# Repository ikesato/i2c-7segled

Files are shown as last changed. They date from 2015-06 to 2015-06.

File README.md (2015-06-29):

概要
====

- I2C を使用した7セグメントLED表示器です
- おもに Raspberry PI からの利用を想定してます  
 Raspberry PI からシェルコマンドを利用して直接制御可能
- 点滅、スクロール機能
- 最大で８つのページ切り替え機能

### パーツ

- PIC18F14K50 (SOIC)  
 1.25mm ピッチ

- TD62083 (SOIC)  
 1.25mm ピッチ

- ダイナミック接続４桁高輝度赤色７セグメントＬＥＤ表示器　カソードコモン　カソード共通接続  
 http://akizukidenshi.com/catalog/g/gI-03955/

- チップ抵抗  
 270Ω  1/4W x 8  

- チップコンデンサ  
 0.1uF  x2

### I2C通信仕様

- 通信速度 100kHz
- I2C スレーブ
- ライト要求 (Master -> Slaveへのライト要求) のみ

### コマンド

| address | data | description |
|---|---|---|
| 0x00 | なし | リセット |
| 0x01 | なし | LCD消灯 |
| 0x02 | 1..8 | 最大ページ数設定  |
| 0x03 | 0..255 | スクロール速度設定 (0.1秒 * (指定値+1)) *1  |
| 0x04 | 0..255 | ページ切り替え速度設定 (0.1秒 * (指定値+1))  |
| 0x05 | 0..255 | 点滅速度設定 (0.1秒 * (指定値+1))  |
| 0x06 | 0..1 | スクロール設定 (0:disable 1:enable)|
| 0x07 | 0..1 | 点滅設定 (0:disable 1:enable) |
| 0x10 | 0..7 | カレントページ設定 *2 |
| 0x11 | 文字列 | 描画文字列を指定、終端は 0x00 を指定します *3 |

*1 ... 文字のスクロール速度になります。例えば 19 を指定した場合 0.1*(19+1) で2秒単位にスクロールします。  
*2 ... 0 から数えるページ数を指定します。範囲は 0 から 最大ページ数-1 になります。  
*3 ... 描画文字列は ASCII コードで指定します。表示可能文字は数字、スペース、ハイフン、アンダースコア、パイプ、アルファベット（大文字、小文字）、ピリオドです。  

### 回路図

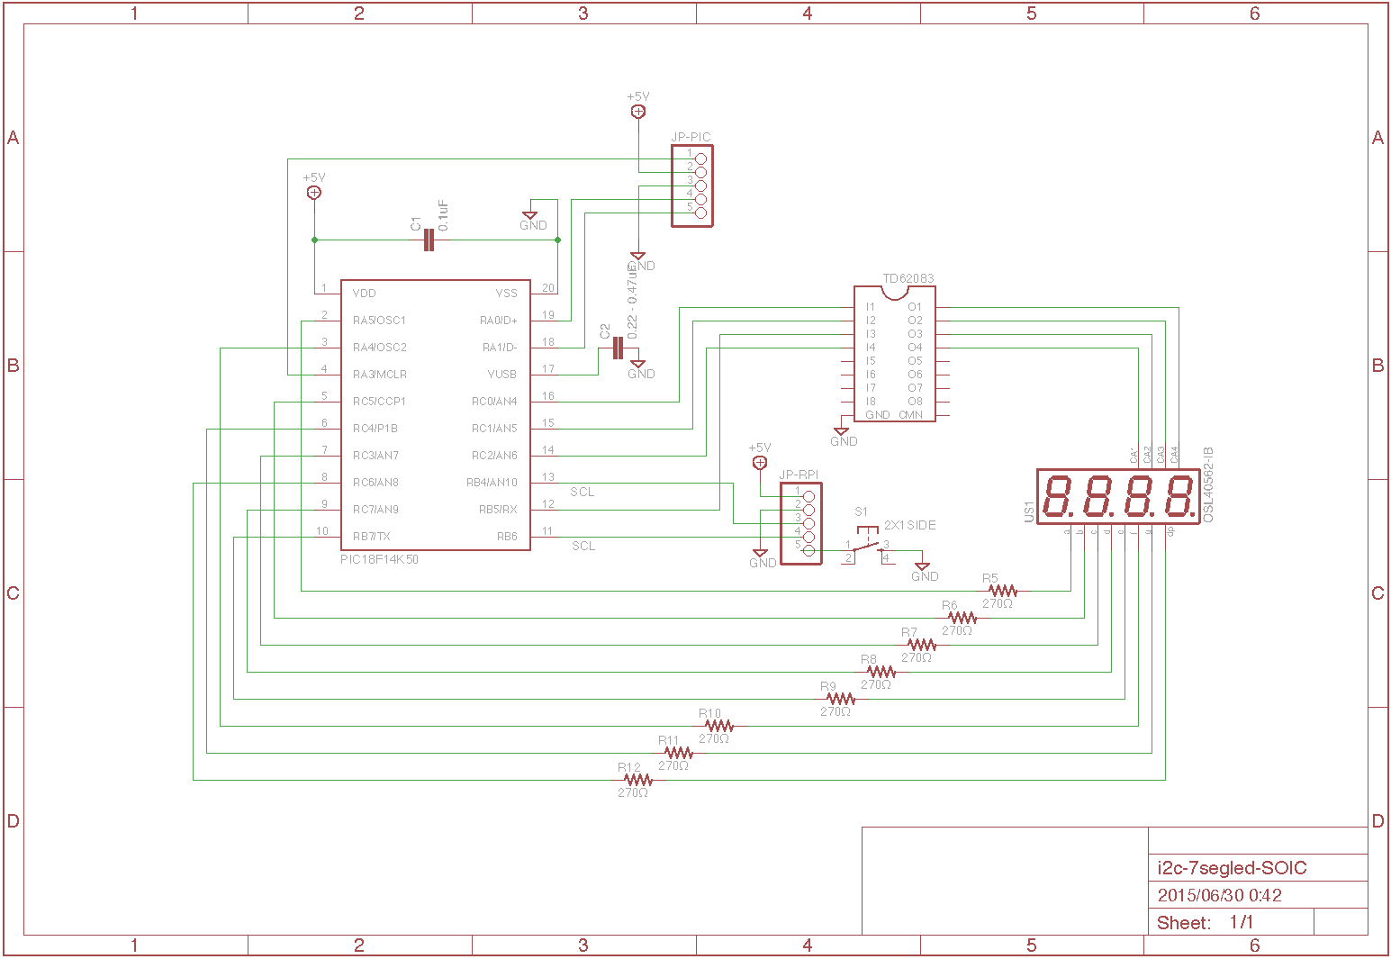
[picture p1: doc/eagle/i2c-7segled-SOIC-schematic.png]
回路図


[EAGLE ファイル](./doc/eagle/i2c-7segled-SOIC.sch)

### ボード

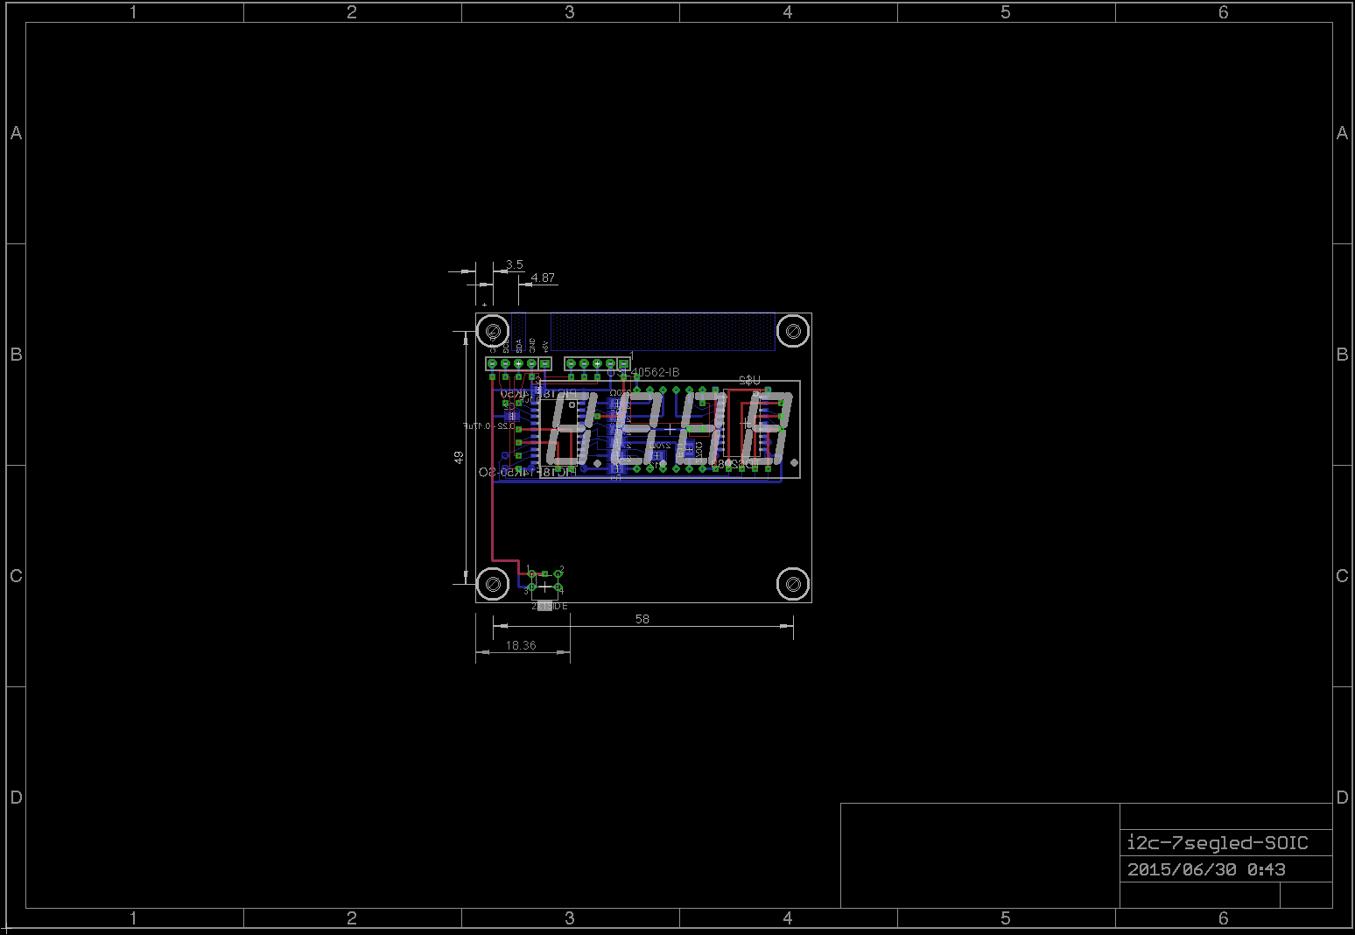
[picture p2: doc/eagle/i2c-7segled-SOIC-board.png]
ボード


[EAGLE ファイル](./doc/eagle/i2c-7segled-SOIC.brd)

### Unix シェルでの使用方法

shell ディレクトリにあるシェルコマンド利用することで簡単に LED を制御できます。

|コマンド |引数  |説明 |
|---|---|---|
|7seg_clear |なし  |7seg LCD をクリアします|
|7seg_enable_blink |0..1  |点滅設定 (0:disable 1:enable)|
|7seg_enable_scroll |0..1  |スクロール設定 (0:disable 1:enable)|
|7seg_puts |文字列|描画文字列を指定|
|7seg_puts_from_stdin  |なし  |文字列を標準入力からリードして描画します。CTRL-C で中断するまで続けます。|
|7seg_reset |なし  |リセット、内部変数ふくめ全て初期化します|
|7seg_set_blink_speed  |0..255| 点滅速度設定 (0.1秒 * (指定値+1))  |
|7seg_set_current_page |0..7  | カレントページ設定 |
|7seg_set_flip_speed |0..255| ページ切り替え速度設定 (0.1秒 * (指定値+1))  |
|7seg_set_page_num |1..8  | 最大ページ数設定  |
|7seg_set_scroll_speed |0..255| スクロール速度設定 (0.1秒 * (指定値+1))  |

例
```````````````````
cd shell
./7seg_reset
./7seg_enable_scroll 1
./7seg_set_scroll_speed 10
./7seg_puts "HELLO"
```````````````````

### 仕様

| 機能 | 仕様  |
|---|---|
|インターフェース |I2Cスレーブ |
|I2Cスレーブアドレス|0x70 |
|I2C転送速度 |100kHz |
|最大表示文字数 |終端NULL含めて200文字。複数ページの場合は各ページの終端NULL含めて合計で200文字|
|使用可能文字 |ASCII コードでスペース、ハイフン、アンダースコア、パイプ、アルファベット（大文字、小文字）、ピリオド|
|最大ページ数 |8ページ|
|表示機能 |ページ切り替え、文字スクロール、点滅、クリア|

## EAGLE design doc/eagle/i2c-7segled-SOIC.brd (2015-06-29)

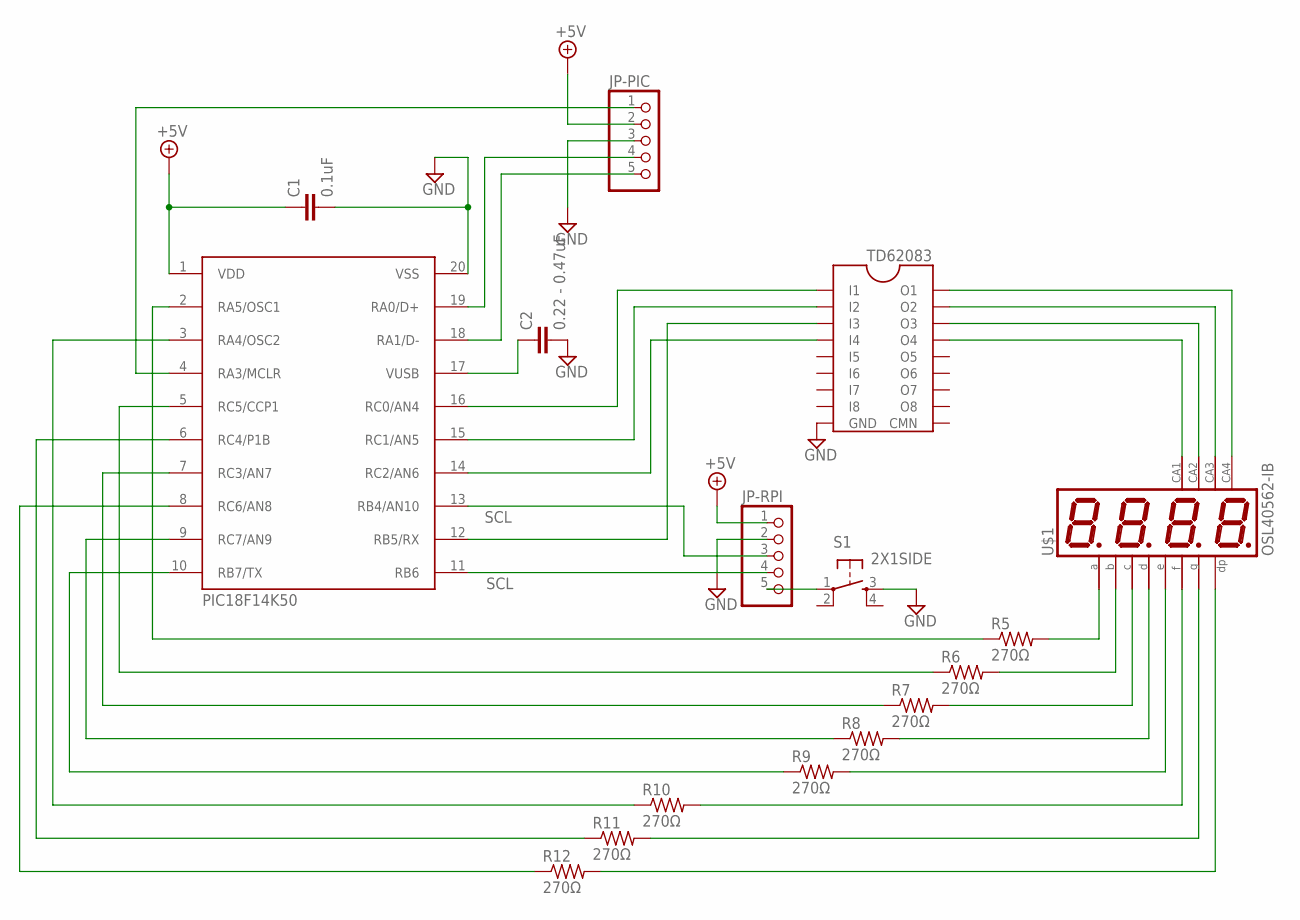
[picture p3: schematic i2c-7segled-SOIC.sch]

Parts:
C1: 0.1uF; C0504
C2: 0.22 - 0.47uF; C0504
JP-PIC: PINHD-1X5; 1X05
JP-RPI: PINHD-1X5; 1X05
PIC18F14K50: PIC18F14K50-SO; SO20
R5, R6, R7, R8, R9, R10, R11, R12: 270Ω; M0805
S1: 2X1SIDE
U$1: OSL40562-IB; OSL40562
U$2: TD62083; SO18

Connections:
+5V: C1.1, JP-PIC.2, JP-RPI.1, PIC18F14K50.1 (VDD)
GND: C1.2, C2.2, JP-PIC.3, JP-RPI.2, PIC18F14K50.20 (VSS), S1.3 (S), U$2.9 (GND)
unnamed: U$1.6 (CA), U$2.18 (O1)
unnamed: C2.1, PIC18F14K50.17 (VUSB)
unnamed: PIC18F14K50.12 (RB5/RX), U$2.3 (I3)
unnamed: JP-RPI.5, S1.1
unnamed: PIC18F14K50.14 (RC2/AN6), U$2.4 (I4)
unnamed: PIC18F14K50.15 (RC1/AN5), U$2.2 (I2)
unnamed: PIC18F14K50.16 (RC0/AN4), U$2.1 (I1)
unnamed: U$1.9 (CA), U$2.16 (O3)
unnamed: U$1.8 (CA), U$2.17 (O2)
unnamed: U$1.12 (CA), U$2.15 (O4)
unnamed: PIC18F14K50.2 (RA5/OSC1), R5.1
unnamed: R5.2, U$1.11 (A)
unnamed: PIC18F14K50.5 (RC5/CCP1), R6.1
unnamed: PIC18F14K50.7 (RC3/AN7), R7.1
unnamed: PIC18F14K50.9 (RC7/AN9), R8.1
unnamed: PIC18F14K50.10 (RB7/TX), R9.1
unnamed: PIC18F14K50.3 (RA4/OSC2), R10.1
unnamed: PIC18F14K50.6 (RC4/P1B), R11.1
unnamed: PIC18F14K50.8 (RC6/AN8), R12.1
unnamed: R6.2, U$1.7 (B)
unnamed: R7.2, U$1.4 (C)
unnamed: R8.2, U$1.2 (D)
unnamed: R9.2, U$1.1 (E)
unnamed: R10.2, U$1.10 (F)
unnamed: R11.2, U$1.5 (G)
unnamed: R12.2, U$1.3 (DP)
unnamed: JP-PIC.1, PIC18F14K50.4 (RA3/MCLR)
unnamed: JP-PIC.4, PIC18F14K50.19 (RA0/D+)
unnamed: JP-PIC.5, PIC18F14K50.18 (RA1/D-)
unnamed: JP-RPI.4, PIC18F14K50.11 (RB6)
SCL: JP-RPI.3, PIC18F14K50.13 (RB4/AN10)

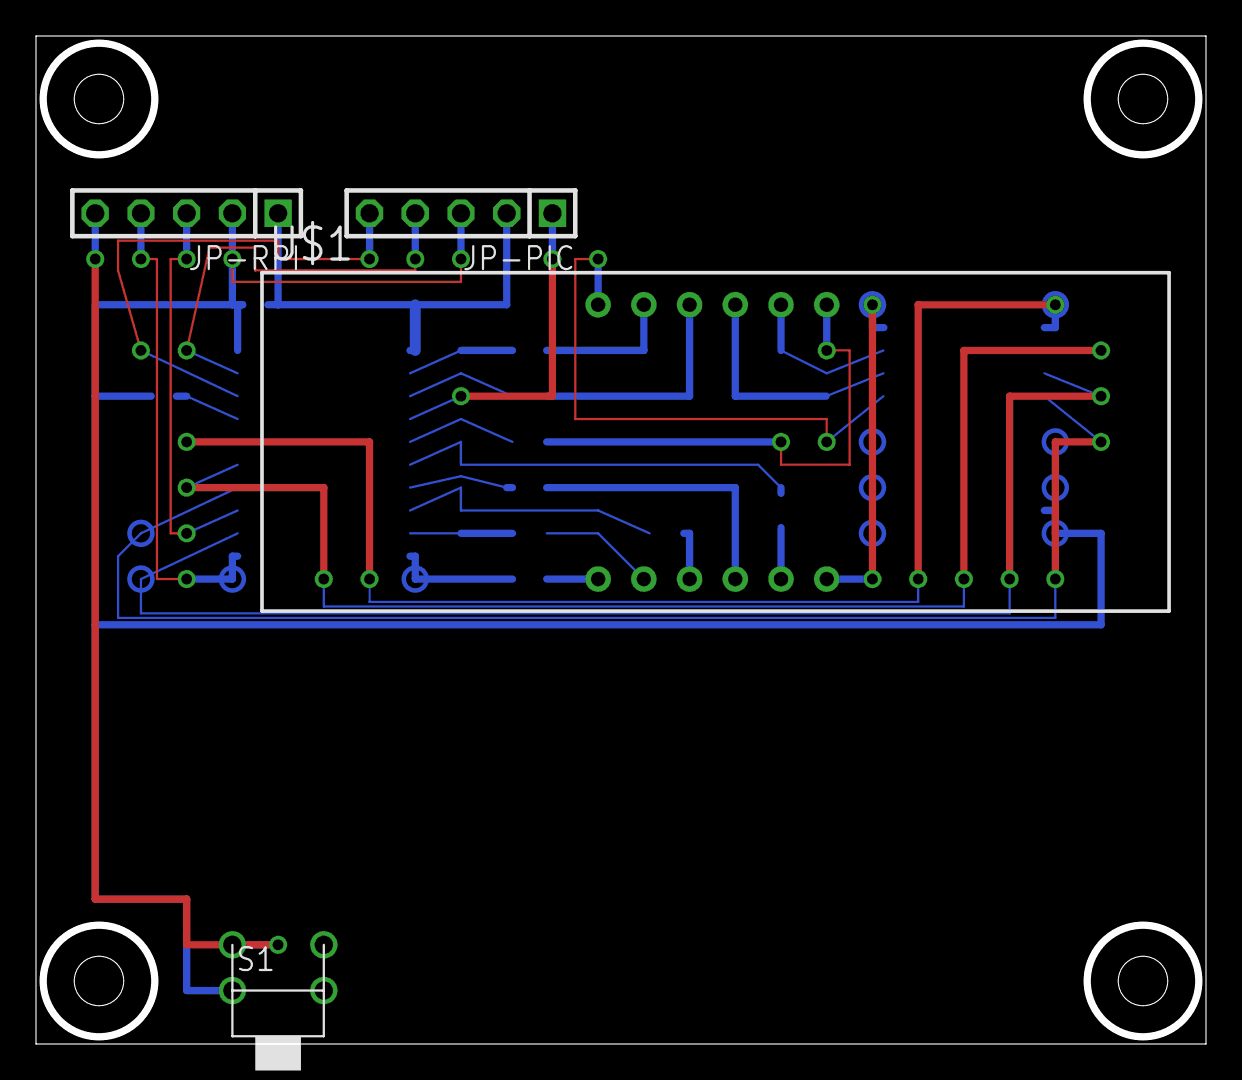
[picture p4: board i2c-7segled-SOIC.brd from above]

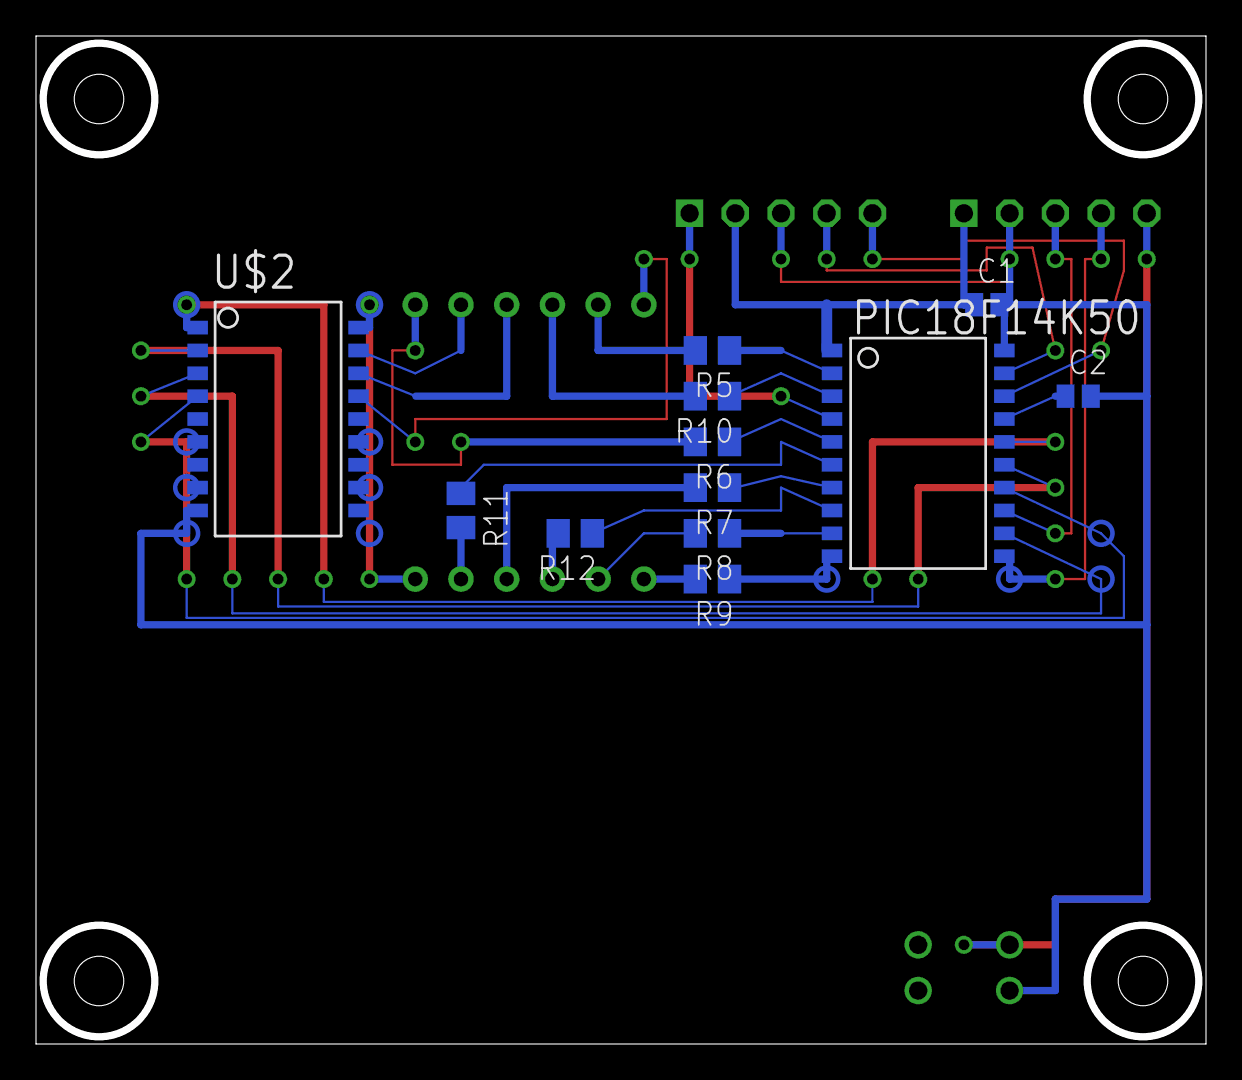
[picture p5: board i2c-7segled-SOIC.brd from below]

Board: 2 copper layers, 65.0 x 56.0 mm, 17 parts (12 on the bottom side), 33 nets.

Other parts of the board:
U$3: A4L-LOC

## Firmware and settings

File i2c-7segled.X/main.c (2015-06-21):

#include <p18cxxx.h>
#include <delays.h>
#include "seg7lcd.h"
#include "i2c_slave.h"

#pragma config MCLRE = OFF  // MCLR PIN ENABLE BIT
#pragma config FOSC  = IRC  // Internal clock
#pragma config LVP   = OFF  // Single-Supply ICSP Enable bit
#pragma config WDTEN = OFF  // Watchdog Timer Enable bit

#define T0CNT 4
#define OVERFLOW_MSEC   (8064L)   // Timer overflow frequency [us]
#define ONE_SEC         ((LONG)(1000L * 1000L / OVERFLOW_MSEC))  // one second of WORD value
#define BASE_TIME       (unsigned char)(ONE_SEC*0.1)

static unsigned long gcounter = 0;     // global counter
static unsigned char timer = 0;
static char lcd_buffer[255];
static char current_page = 0;

/**
 * !@brief Interrupt function
 */
void interrupt interrupt_func(void)
{
  // timer interrupt
  if (T0IF == 1) {
    TMR0 = T0CNT;
    T0IF = 0;
    gcounter++;
    if (++timer > BASE_TIME) {
      seg7lcd_sync();
      timer = 0;
    }
  }

  // I2C interrupt handler
  i2cs_interrupt();
}



void init(void) {
  OSCCON = 0x52;      // 4MHZ
  TRISA = 0;
  TRISB = 0;
  TRISC = 0;
  PORTA = 0;
  PORTB = 0;
  PORTC = 0;
  ANSELH = 0;
  ANSEL = 0;

  // timer
  // timer cycle => 8064 usec
  // 8064usec is most close to generage 1sec
  // 8064 * 124 = 999,936[usec]
  TMR0ON = 1;
  T08BIT = 1;
  T0CONbits.T0PS = 0b100; // prescaler 1:32
  TMR0 = T0CNT;
  TMR0IP = 1;
  TMR0IE = 1;
  TMR0IF = 0;
  T0CS = 0;
  PSA = 0;
  IPEN = 1;
  GIEH = 1;
  GIEL = 1;

  i2cs_init(0x70);
  seg7lcd_init(lcd_buffer, sizeof(lcd_buffer));
  seg7lcd_clear();
}


void main(void) {
  int ans;
  char send_data;

  init();

  while(1) {
    ans = i2cs_proc();
    if (ans != 0) {
      char *recv_buff = i2cs_read_recv_buff(NULL, 0);
      switch(recv_buff[0]) {
      case 0x00:
        seg7lcd_reset();
        break;
      case 0x01:
        seg7lcd_clear();
        break;
      case 0x02:
        seg7lcd_set_page_num(recv_buff[1]);
        break;
      case 0x03:
        seg7lcd_set_scroll_speed(recv_buff[1]);
        break;
      case 0x04:
        seg7lcd_set_flip_speed(recv_buff[1]);
        break;
      case 0x05:
        seg7lcd_set_blink_speed(recv_buff[1]);
        break;
      case 0x06:
        seg7lcd_enable_scroll(recv_buff[1]);
        break;
      case 0x07:
        seg7lcd_enable_blink(recv_buff[1]);
        break;
      case 0x10:
        current_page = recv_buff[1];
        break;
      case 0x11:
        seg7lcd_puts(current_page, &recv_buff[1]);
        break;
      }
    }

    seg7lcd_draw();
  }
}

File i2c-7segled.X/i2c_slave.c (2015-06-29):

#include <p18cxxx.h>
#include <htc.h>
#include <string.h>
#include "i2c_slave.h"

#define SEND_BUFF_LEN 1                  // Send buffer size
#define RECV_BUFF_LEN 200                // Receive buffer size

unsigned char recv_buff[RECV_BUFF_LEN];  // Send buffer
unsigned char send_buff[SEND_BUFF_LEN];  // Receive bufer

unsigned int  recv_size;     // Receive data size
unsigned char *sdtp;         // A Pointer of send buffer
unsigned char *rdtp;         // A Pointer of receive buffer


/**
 * !@brief Interrupt function for I2C slave
 */
void i2cs_interrupt(void)
{
  char x;

  if (SSPIF == 1) {
    if (SSPSTATbits.R_nW == 0) {
      // Write Command from Master (Slave is recieving data)
      if (SSPSTATbits.D_nA == 0) {
        rdtp = recv_buff;
        x = SSPBUF;        // Skip address buffer
        recv_size = 0;
      } else {
        *rdtp = SSPBUF;    // Read data
        rdtp++;
        recv_size++;
      }
      SSPIF = 0;             // Clear interrupt flag
      SSPCON1bits.CKP = 1;   // Release SCL
    } else {
      // Read Command from Master (Slave is sending data)
      if (SSPSTATbits.BF == 1) {
        sdtp = send_buff;
        x = SSPBUF;        // Skip address buffer
        while(SSPCON1bits.CKP | SSPSTATbits.BF);
        SSPBUF = *sdtp++;  // Set sending data
        SSPIF = 0;
        SSPCON1bits.CKP = 1;
      } else {
        if (SSPCON2bits.ACKSTAT==0) {
          // ACK from Master
          while((SSPCON1bits.CKP)|(SSPSTATbits.BF));
          SSPBUF = *sdtp++;
          SSPIF = 0;
          SSPCON1bits.CKP = 1;
        } else {
          // NACK from Master
          SSPIF = 0;
        }
      }
    }
  }

  // MSSP Bus Collision Interrupt
  if (BCLIF == 1) {
    BCLIF = 0;   // Clear only
  }
}


/**
 * !@brief Initilize function for I2C slave
 *
 * @param[in] address Slave address
 */
void i2cs_init(int address)
{
  RABPU = 0;                  // Use inernal pull up register
  WPUB4 = 1;                  // pull up for SDA
  WPUB6 = 1;                  // pull up for SCL
  TRISB4 = 1;                 // SDA as input
  TRISB6 = 1;                 // SCL as input
  SSPSTAT= 0b10000000;        // normal speed, 100kHz.
  SSPCON1= 0b00100110;        // Slave mode, Use SDA/SCL, 7bit address
  SSPCON2bits.SEN  = 1;       // Enable Clock stretching
  SSPADD = address<<1;        // Set slave address
  SSPMSK = 0b11111110;        // Set address mask
  SSPIE  = 1;                 // Enable interrupt
  BCLIE  = 1;                 // Enable MSSP(I2C) Bus Collision interrupt
  PEIE   = 1;                 // Enable Peripheral interrupt
  GIE    = 1;                 // Enable Global interrupt
  SSPIF  = 0;                 // Clear SSP(I2C) interrupt flag
  BCLIF  = 0;                 // Clear MSSP(I2C) interrupt flag
  recv_size = 0;
}


/**
 * !@brief I2C process function
 *
 * This function should call from main loop
 * @return Receive size of Writing data from Master. 0 means no data received, other means receieve data size.
 */
int i2cs_proc()
{
  int ans;

  ans = 0;
  if (recv_size != 0) {
    if ((SSPSTATbits.S==0) && (SSPSTATbits.P==1)) { // Detected stop condition
      ans = recv_size;
      recv_size = 0;
    }
  }
  return(ans);
}

/**
 * !@brief Read received data
 *
 * @param[out] buff An address of buffer for output. If buff is NULL, return a pointer of receive buff.
 * @param[in] size A size of buff [Byte].
 * @return If buff is not NULL, return buff address. Otherwise buff is NULL, Return a pointer of receive buffer.
 */
char *i2cs_read_recv_buff(char *buff, unsigned char size)
{
  if (buff != NULL) {
    memcpy(buff, recv_buff, size);
    return buff;
  } else {
    return recv_buff;
  }
}

/**
 * !@brief Set send data
 *
 * @param[in] buff An address of buffer for sending.
 * @param[in] size A size of buff [Byte].
 */
void i2cs_set_send_buff(char *buff, unsigned char size)
{
  memcpy(send_buff, buff, size);
}

/**
 * !@brief Get send data buffer
 *
 * @return A buffer of send data.
 */
char *i2cs_get_send_buff(void)
{
  return send_buff;
}

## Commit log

2015-06-02 implement upper case of font
2015-06-07 implment lower case fonts
2015-06-19 implemented i2c
2015-06-19 add i2c specification
2015-06-20 add i2c command for clear
2015-06-21 refactoring commit. change word 'rotate' to 'flip'.
    [main.c]
2015-06-21 fix wrong strings pointer problem
    [main.c]
2015-06-21 add eagle documents
    [i2c-7segled-SOIC.brd, i2c-7segled-SOIC.sch]
2015-06-24 remove unnecessary wires for borad documents
    [i2c-7segled-SOIC.brd]
2015-06-29 update eagle documents
    [i2c-7segled-SOIC.brd, i2c-7segled-SOIC.sch]
2015-06-29 add I2C slave address in specifications
